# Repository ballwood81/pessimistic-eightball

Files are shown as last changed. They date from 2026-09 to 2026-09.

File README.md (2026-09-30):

# Pessimistic Eight Ball

A sarcastic fortune teller for the Seeed Studio XIAO nRF52840 Sense and Round Display for XIAO.

Shake it deliberately and the idle face gives way to a 900 ms mystic reveal. One of 48 yes, no, maybe, or ominous predictions remains visible for 15 seconds before the face returns.

Parametric enclosure source, printable parts, test coupons, and assembly notes
are in [cad/](cad/README.md).

## Hardware

- Seeed Studio XIAO nRF52840 Sense
- Seeed Studio Round Display for XIAO, 240 x 240 GC9A01
- USB data cable connected to the **XIAO USB-C port** for programming

The accelerometer is the XIAO Sense's onboard LSM6DS3TR-C. The Round Display provides the LCD, touch controller, RTC, and microSD slot.

The microSD card is not used. It is unnecessary for procedural graphics and static text, and Seeed documents support for FAT cards only up to 32 GB; the installed 64 GB card is outside that specification.

## Build and upload

Install the PlatformIO extension in VS Code, then run:

```powershell
pio run -e xiao_nrf52840_sense
pio run -e xiao_nrf52840_sense --target upload
```

If no USB serial device appears, ensure the cable is connected to the XIAO rather than the Round Display's power/charging USB-C port. Double-press the XIAO reset button to enter its UF2 bootloader, then retry upload.

## Tests

Logic tests cover shake discrimination, hit-window expiry, response repetition, reveal timing, busy-state lockout, and `millis()` rollover.

Run them on the attached XIAO:

```powershell
pio test -e xiao_tests
```

The `native` test environment is also configured, but requires `gcc` and `g++` on `PATH`:

```powershell
pio test -e native
```

## Tuning

Shake sensitivity is controlled by `ShakeConfig` in [include/eight_ball_logic.h](include/eight_ball_logic.h). Defaults require three acceleration deviations of at least 0.65 g within 400 ms. This rejects ordinary tilt because it uses acceleration magnitude rather than any single axis.

Predictions live in [include/responses.h](include/responses.h). Keep additions fairly short so they fit within six 20-character lines on the round display.

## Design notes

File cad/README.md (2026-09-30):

# Pessimistic Eight Ball enclosure

Parametric Build123d source for a PETG, 150 mm spherical enclosure. This is a
reviewable first-print design, not a verified production fit.

## Generate

Python 3.10 is the minimum; Python 3.11+ is recommended.

```powershell
python -m pip install -r cad/requirements.txt
python -m cad.export
```

Outputs are written to `cad/out/`:

- `upper_shell.{step,stl}`
- `lower_shell.{step,stl}`
- `usb_strain_relief.{step,stl}`
- `display_mount_coupon.{step,stl}`
- `bayonet_{female,male}_test_ring.{step,stl}`
- `battery_cradle_fit_test.{step,stl}`
- `assembled.step`, `exploded.step`
- `assembly_preview.png`, `exploded_preview.png`
- `verification.txt`

Edit `cad/params.py`, then regenerate. All dimensions are millimetres.

## Dimension status

Physically tested:

- Display aperture: **43.5 mm exactly**. No added clearance.
- Display support contact face: **9.0 mm** behind the exterior face.

Verified from both official Seeed Eagle boards:

- v1.0 and v1.1 mounting holes are identical: `(0, 19.431)`,
  `(11.811, -15.621)`, `(-11.811, -15.621)`, drill 2.2 mm.
- Printed ledge holes are 2.4 mm for M2 fit testing.
- Seeed describes the board as 39 mm. v1.1 changes the charge IC and adds the
  two-position switch; this model defaults to the larger v1.1 rear keep-out.
- Facing the glass, XIAO USB-C points right and the display switch is lower
  left, matching [Seeed's documented orientation][seeed].

Provisional and deliberately adjustable:

- 3.0 mm shell; 65 mm base footprint; 40 degree display angle.
- 2.5 mm curved ledges. Their shape follows the supplied screenshots: three
  local arcs around the 43.5 mm opening, with deeper root ribs. Screenshot
  construction points were not used as screw centres.
- Bayonet radial clearance 0.35 mm per side; axial 0.30 mm; tangential
  0.40 mm. Detent depth, clip retention, and shake resistance are untested.
- Battery pocket 0.6 mm clearance; clips 1.8 mm thick with 1.2 mm overlap.
- Moulded USB plug envelope 12.5 x 7 x 22 mm and 15 mm bend radius.
- Three-wire service connector envelope. `JST-XH 3-pin` is only a planning
  placeholder; set dimensions to the connector actually fitted.

## Design

The sphere is split at its equator. A derived internal collar carries three
120-degree bayonet lugs. Travel is 25 degrees. Entry slots have lead-ins;
tracks have positive end walls, radial detent bumps, and an inner wire guard.
One wide and one narrow seam notch form discreet insertion marks.

The upper face is a plane normal to a ray 40 degrees from vertical. Its
distance is derived from a 50 mm sphere chord. The 43.5 mm aperture is cut
normal to that plane. Three curved 2.5 mm ledges place their PCB contact faces
9 mm behind the exterior. Nut pockets are in thicker rear bosses, not in the
ledges.

Use three M2 x 6 mm pan-head screws and M2 nuts as the first stack trial:
1.6 mm reference PCB + 2.5 mm ledge + 1.6 mm nut. Verify the actual board,
head seating, nut engagement, and tip clearance before powering it. The
fasteners load the PCB mounting holes; they must not clamp the glass.

The reference snap case is 71.5 mm long and suits two loose cells with a gap
between them. This cradle is one channel for the shrink-wrapped pair: 4 mm
longer than that case, and 1 mm taller than the 19 mm pack body for the wrap.
Side hooks cam open and close over the pack. They stop before the 21 mm cable
end. There is no center divider. The cable end of the channel is open in the
middle. Route all three wires out that opening to a removable three-pin
connector inside the track guard.
Unplug it before separating the halves.

The rear upper-shell USB opening passes the full provisional moulded plug and
stays above the bayonet. Direct alignment to the sideways XIAO socket is not
practical in this geometry. Fit a short panel-free USB-C male-to-female
extension internally. Secure its cable jacket with the separate M2 strain
relief; do not transfer cable loads to the XIAO socket.

## Assembly order

1. Print and test the display coupon, bayonet rings, and battery cradle.
2. Install M2 nuts in the display bosses. Seat the Round Display without
   loading the active glass, fit the XIAO and headers, then install screws.
3. Fit the USB-C extension and clamp its jacket.
4. Push the battery into the lower cradle, cable end toward the configured
   `+X` end. Connect the removable three-wire lead and leave a service loop.
5. Keep the loop inside the guard, align seam marks, insert the upper half,
   rotate through the detent to the hard stop.
6. To service, rotate back, lift only enough to reach the connector, unplug,
   then separate fully.

## Printing

- Material: PETG. Start with 0.20 mm layers, 4 perimeters, and 5 top/bottom
  layers. Tune from coupons before printing shells.
- Upper shell: place the exterior display plane on the bed. Support is still
  required under portions of the inner sphere, root ribs, nut bosses, and
  bayonet roof. Block support from the 43.5 mm aperture and screw holes.
- Lower shell: flat base on the bed. Use local support only where the collar
  needs it. Clips print vertically so layer lines do not split across their
  root.
- Bayonet rings: flat annular face on the bed.
- Display coupon: exterior face on the bed.
- Battery coupon: cradle floor on the bed. Do not force the wrapped pack into
  an undersized print.

## Verification and outstanding checks

`python -m cad.export` fails if a printable body is not a valid closed solid,
the battery/clip envelope leaves the inner sphere, bayonet entry or locked
positions interfere, the detent has no engagement, the end stop has no
collision, or the USB plug path enters the collar.

CAD checks do not validate printer compensation, PETG creep, clip fatigue,
nut capture, connector orientation, touch access, cable flex life, detent
force, drop strength, or shake resistance. Print the three coupons first.
Measure the actual assembled XIAO/header depth and actual plug/connector before
the full shells.

## Attribution

Bayonet concepts are adapted from Johannes Hermann's
[AC Hose Bayonet Quick Connectors][bayonet], Apache-2.0. This version changes
the lug count, sections, fit model, path, stops, detents, wire guard, and
enclosure integration. See `NOTICE` and `LICENSE-Apache-2.0.txt`.

[bayonet]: https://github.com/jhermann/things/tree/main/models/ac-bayonet-connectors
[seeed]: https://wiki.seeedstudio.com/get_start_round_display/

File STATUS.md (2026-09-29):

# Project status — 2026-09-29 (LVGL polish)

## Diagnosis (pre-change)

| Symptom | Likely cause |
| --- | --- |
| Dirty / flicker | `fillScreen` + full idle-face redraw every 80 ms; no retained scene |
| Tear-ish lines earlier | wrong combo 666 (fixed) then heavy full-frame SPI |
| IMU false/miss | shake counted every sample above threshold with no hysteresis/cooldown; no shared lock vs touch |

## Shipped

- LVGL 8.3.11 + Seeed Round Display (`lv_xiao_*`) + Seeed_GFX combo **501**
- Persistent UI objects; fade + upward drift via `text_opa` / `y` (no full wipe)
- CHSC6X touch via Round Display LVGL indev; tap reveal / tap dismiss
- Shake: enter/exit hysteresis + hit window + cooldown; gated by `BallMachine`
- State: IDLE → TRIGGERED → REVEALING → VISIBLE → RESETTING → IDLE
- Responses unchanged
- Built + DFU flashed (RAM ~20%, flash ~28%)

## Physical test still needed

- Tap feel / debounce on glass
- Shake sensitivity on desk vs hand
- Reveal readability for longest ominous lines
- Auto-timeout vs tap-dismiss race

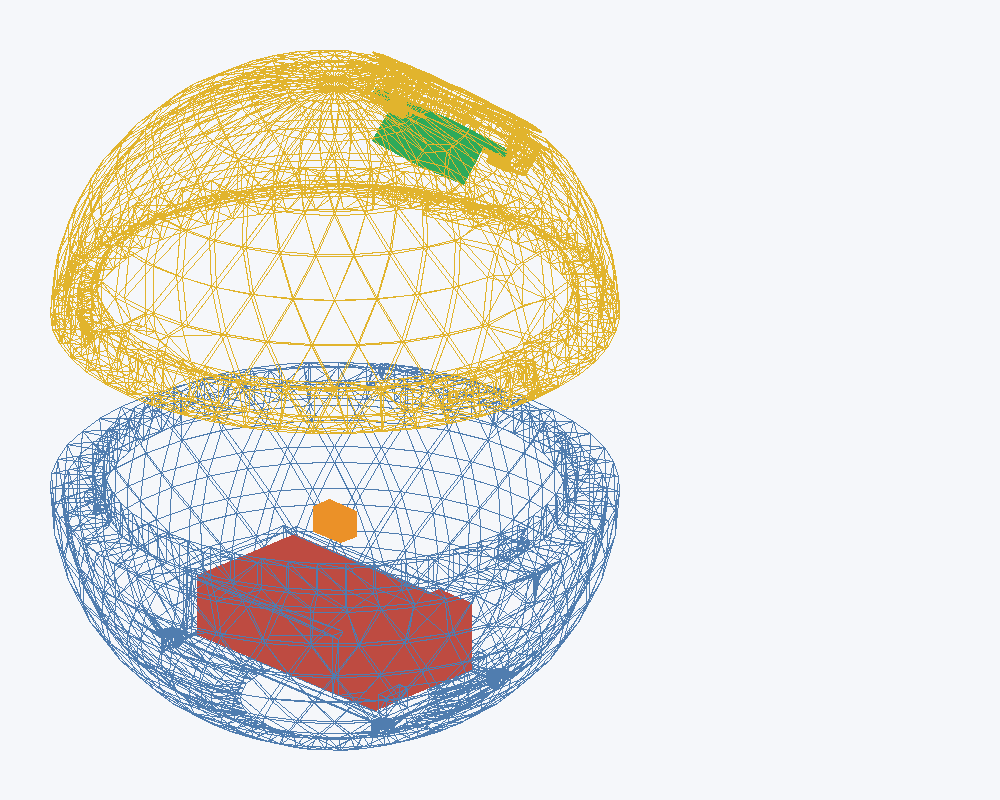
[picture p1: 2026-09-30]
cad/out/exploded_preview.png

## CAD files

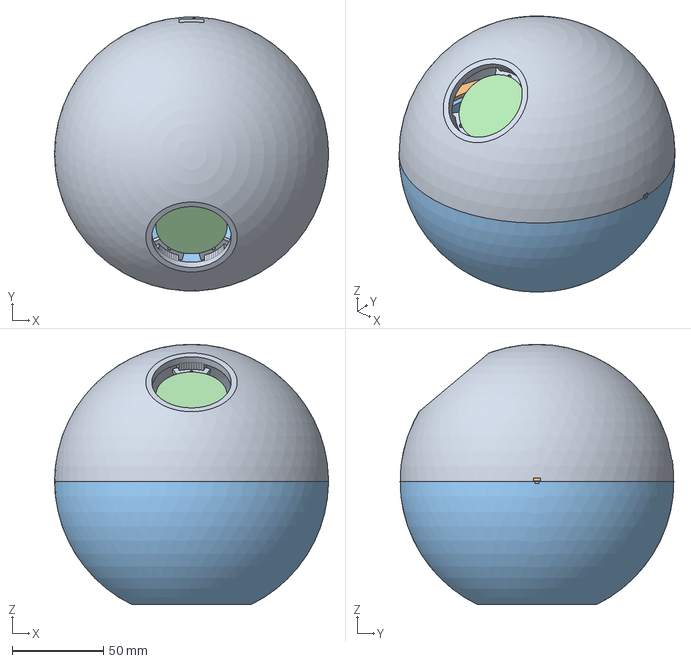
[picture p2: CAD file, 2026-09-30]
cad/out/assembled.step
150.0 x 149.8 x 142.6 mm

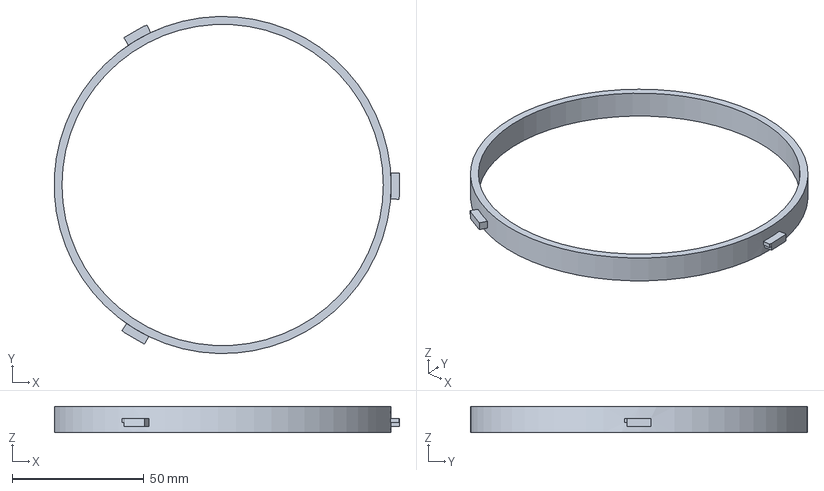
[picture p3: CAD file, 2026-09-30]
cad/out/bayonet_male_test_ring.step
131.0 x 127.8 x 10.0 mm

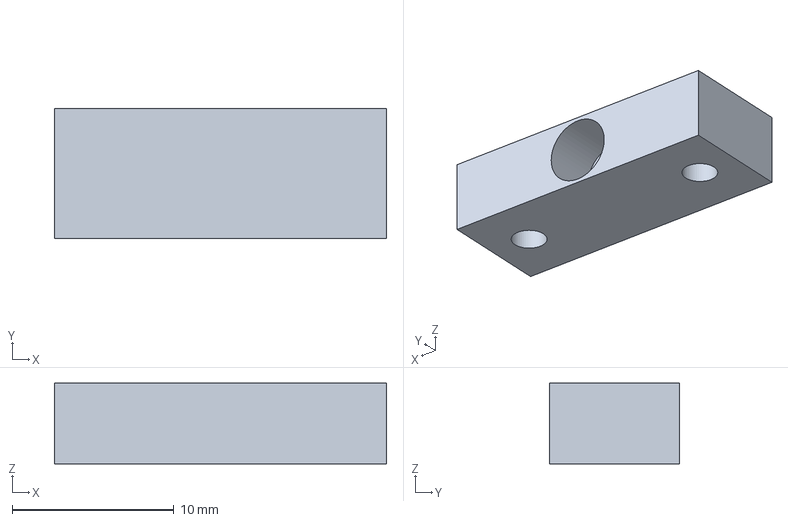
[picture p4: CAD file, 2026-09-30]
cad/out/usb_strain_relief.step
20.5 x 8.00 x 5.00 mm

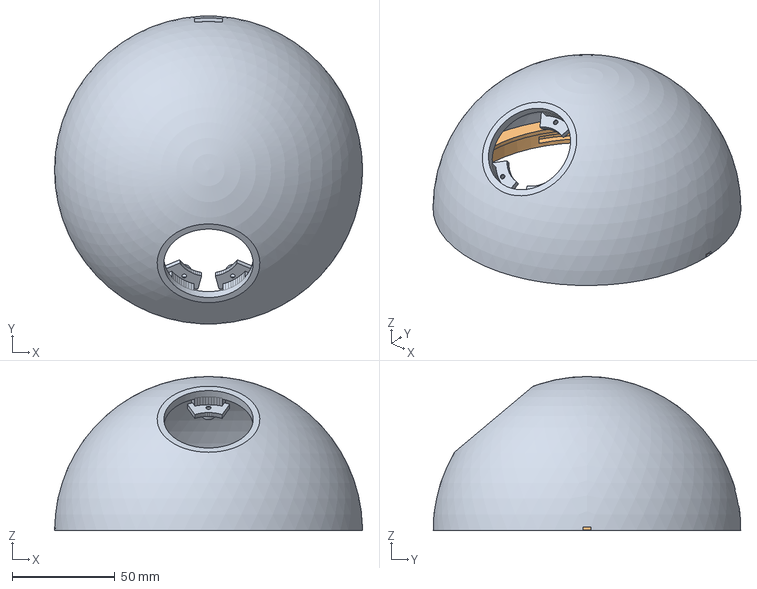
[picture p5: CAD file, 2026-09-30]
cad/out/upper_shell.step
150.0 x 149.8 x 75.0 mm

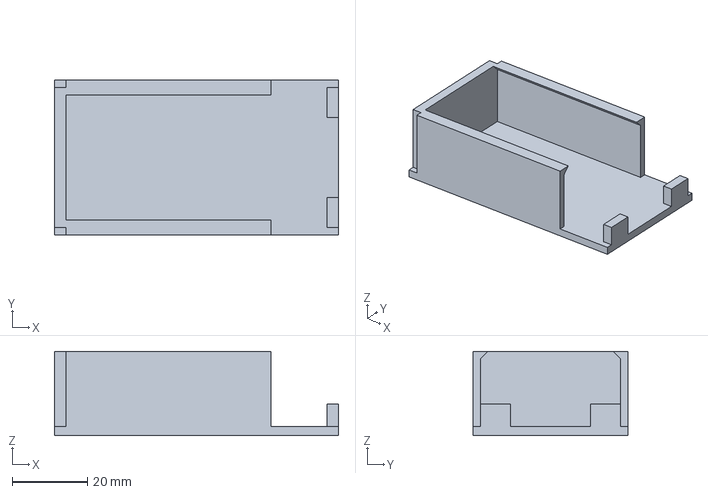
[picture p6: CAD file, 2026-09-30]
cad/out/battery_cradle_fit_test.step
75.5 x 41.2 x 22.4 mm

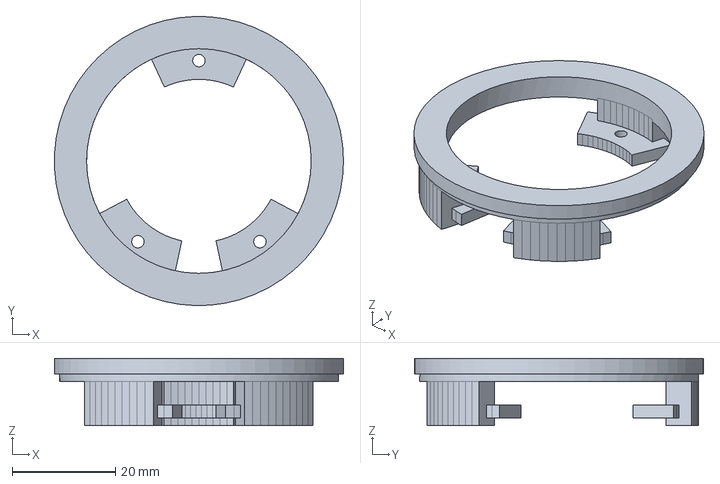
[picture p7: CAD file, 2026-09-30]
cad/out/display_mount_coupon.step
56.0 x 56.0 x 13.0 mm

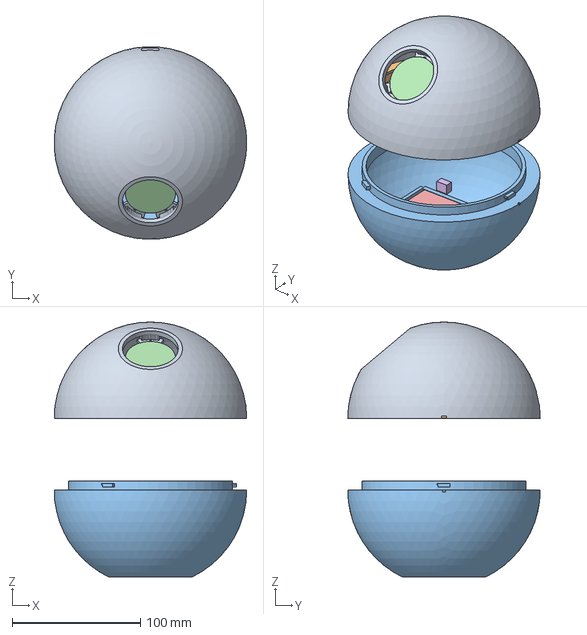
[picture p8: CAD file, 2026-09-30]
cad/out/exploded.step
149.9 x 149.9 x 198.6 mm

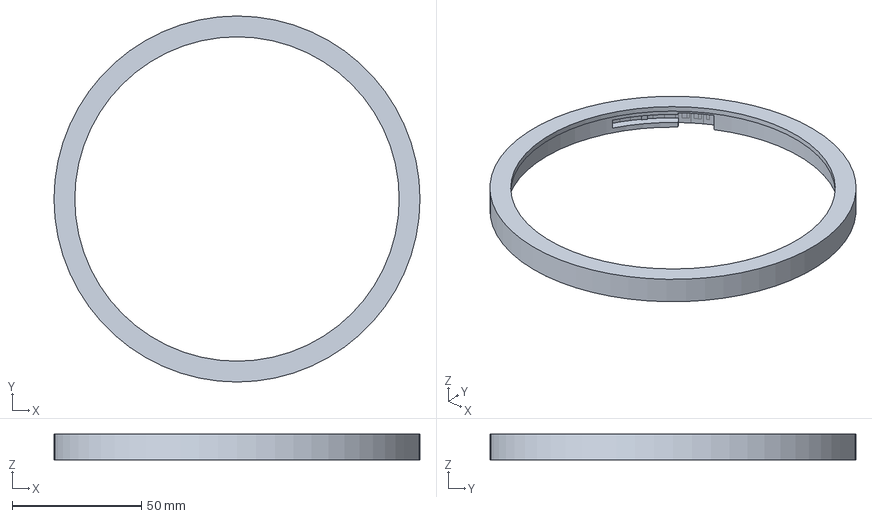
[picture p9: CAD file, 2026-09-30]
cad/out/bayonet_female_test_ring.step
141.7 x 141.7 x 10.0 mm

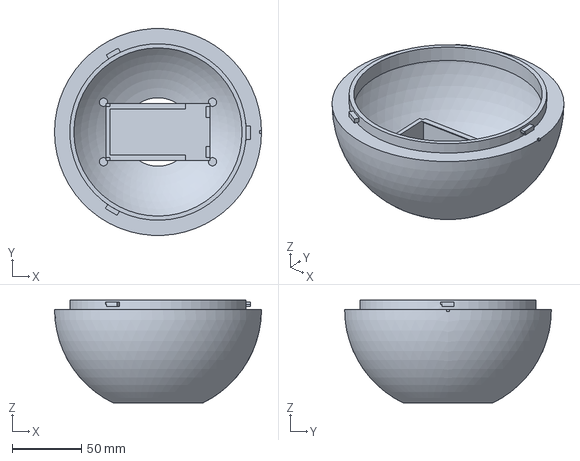
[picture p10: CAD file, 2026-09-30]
cad/out/lower_shell.step
150.0 x 149.8 x 74.6 mm

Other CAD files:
cad/out/battery_cradle_fit_test.stl
cad/out/bayonet_female_test_ring.stl
cad/out/bayonet_male_test_ring.stl
cad/out/display_mount_coupon.stl
cad/out/lower_shell.stl
cad/out/upper_shell.stl
cad/out/usb_strain_relief.stl

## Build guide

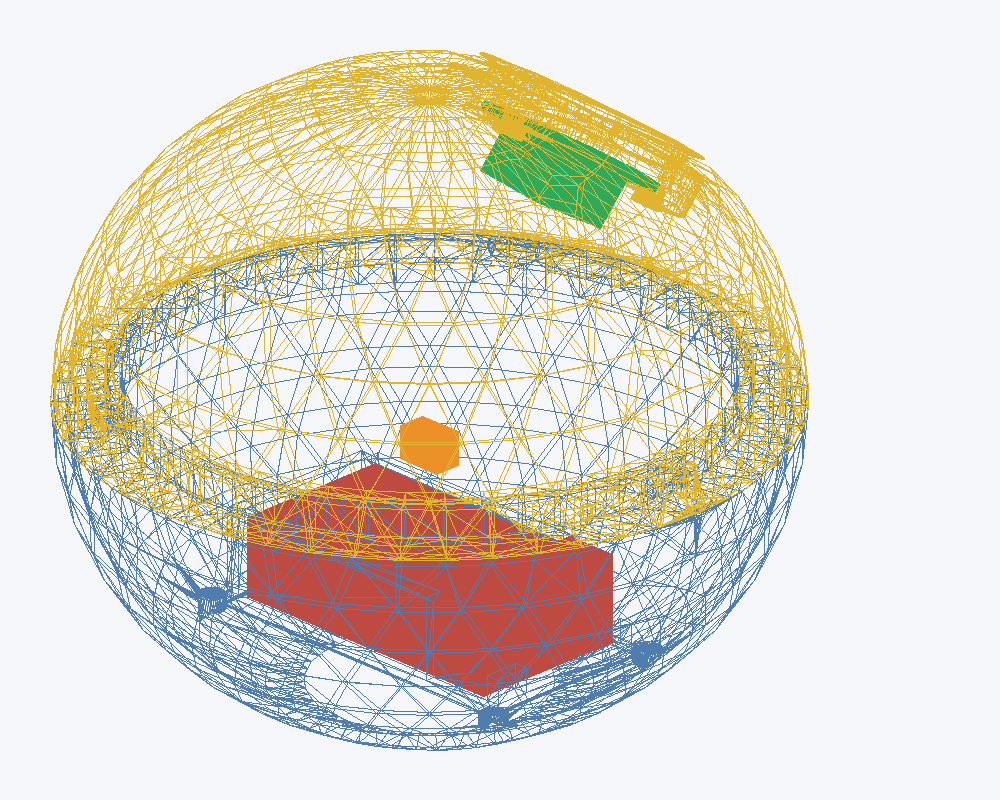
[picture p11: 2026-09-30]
cad/out/assembly_preview.png

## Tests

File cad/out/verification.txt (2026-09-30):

solids: valid closed solids
shell: 3.00 mm nominal
display: 43.5 mm aperture; 9.0 mm setback; 2.5 mm ledges
bayonet: entry 0.000 mm3; detent 5.496 mm3; locked 0.000 mm3; stop 135.508 mm3
battery: pack and clip swept envelope inside inner sphere
usb: plug path clears bayonet collar; internal extension required

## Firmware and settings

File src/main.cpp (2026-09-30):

#include <Adafruit_TinyUSB.h>
#include <Arduino.h>
#include <LSM6DS3.h>
#include <I2C_BM8563.h>
#include <Wire.h>
#include <cmath>
#include <cstdint>
#include <cstdio>

#include "driver.h"
#include <lvgl.h>
#include "lv_xiao_round_screen.h"

#include "eight_ball_logic.h"
#include "responses.h"

namespace {

constexpr std::uint32_t kImuIntervalMs = 20;
constexpr std::int16_t kSafeTextWidth = 168;
constexpr std::int16_t kRevealDriftPx = 18;
constexpr std::uint32_t kAnimMs = 700;

LSM6DS3 imu{I2C_MODE, 0x6A};
I2C_BM8563 rtc{I2C_BM8563_DEFAULT_ADDRESS, Wire};
bool rtc_ok = false;
void refresh_clock();
ShakeDetector shake_detector;
FaceOrient face_orient;
bool imu_ok = false;
ResponsePicker response_picker{kResponseCount};
BallMachine ball;

const Response* current_response = nullptr;
BallState previous_state = BallState::idle;
std::uint32_t last_imu_ms = 0;

lv_obj_t* scr = nullptr;
lv_obj_t* badge = nullptr;
lv_obj_t* eight_mark = nullptr;
lv_obj_t* window = nullptr;
lv_obj_t* eye_l = nullptr;
lv_obj_t* eye_r = nullptr;
lv_obj_t* pupil_l = nullptr;
lv_obj_t* pupil_r = nullptr;
lv_obj_t* mouth = nullptr;
lv_obj_t* clock_label = nullptr;
char clock_text[9] = "--:--:--";
lv_obj_t* kind_label = nullptr;
lv_obj_t* body_label = nullptr;

constexpr std::int16_t kEyeOpen = 28;
constexpr std::int16_t kEyeShut = 5;

lv_color_t kind_color(const ResponseKind kind) {
    switch (kind) {
        case ResponseKind::yes:
            return lv_color_hex(0x3d9b6e);
        case ResponseKind::no:
            return lv_color_hex(0xc44b4b);
        case ResponseKind::maybe:
            return lv_color_hex(0xc4843a);
        case ResponseKind::ominous:
            return lv_color_hex(0x9a5fb5);
    }
    return lv_color_hex(0xd8d0c4);
}

const char* kind_caption(const ResponseKind kind) {
    switch (kind) {
        case ResponseKind::yes:
            return "YES, SOMEHOW";
        case ResponseKind::no:
            return "ABSOLUTELY NOT";
        case ResponseKind::maybe:
            return "ANNOYINGLY MAYBE";
        case ResponseKind::ominous:
            return "THE VOID SAYS";
    }
    return "MYSTIC ERROR";
}

void set_response_hidden(const bool hidden) {
    if (hidden) {
        lv_obj_add_flag(kind_label, LV_OBJ_FLAG_HIDDEN);
        lv_obj_add_flag(body_label, LV_OBJ_FLAG_HIDDEN);
    } else {
        lv_obj_clear_flag(kind_label, LV_OBJ_FLAG_HIDDEN);
        lv_obj_clear_flag(body_label, LV_OBJ_FLAG_HIDDEN);
    }
}

void set_face_hidden(const bool hidden) {
    const lv_obj_t* parts[] = {badge, eye_l, eye_r, pupil_l, pupil_r, mouth, clock_label};
    for (const auto* part : parts) {
        if (hidden) {
            lv_obj_add_flag(const_cast<lv_obj_t*>(part), LV_OBJ_FLAG_HIDDEN);
        } else {
            lv_obj_clear_flag(const_cast<lv_obj_t*>(part), LV_OBJ_FLAG_HIDDEN);
        }
    }
}

void tick_face(const std::uint32_t now_ms) {
    if (ball.state() != BallState::idle) {
        return;
    }
    static std::uint32_t last_tick_ms = 0;
    if (now_ms - last_tick_ms < 80U) {
        return;
    }
    last_tick_ms = now_ms;

    const bool blink = (now_ms % 4300U) < 180U;
    const auto eye_h = static_cast<std::int16_t>(blink ? kEyeShut : kEyeOpen);
    lv_obj_set_height(eye_l, eye_h);
    lv_obj_set_height(eye_r, eye_h);

    constexpr std::int8_t looks[] = {-6, -3, 0, 4, 7, 2, -2};
    const auto look = looks[(now_ms / 700U) % 7U];
    if (blink) {
        lv_obj_add_flag(pupil_l, LV_OBJ_FLAG_HIDDEN);
        lv_obj_add_flag(pupil_r, LV_OBJ_FLAG_HIDDEN);
    } else {
        lv_obj_clear_flag(pupil_l, LV_OBJ_FLAG_HIDDEN);
        lv_obj_clear_flag(pupil_r, LV_OBJ_FLAG_HIDDEN);
        lv_obj_align(pupil_l, LV_ALIGN_CENTER, look, 0);
        lv_obj_align(pupil_r, LV_ALIGN_CENTER, look, 1);
    }

    const auto wobble = static_cast<std::int16_t>((now_ms / 550U) % 3U);
    lv_obj_align(mouth, LV_ALIGN_CENTER, 0, static_cast<std::int16_t>(46 + wobble));

    static std::uint32_t last_clock_ms = 0;
    if (!rtc_ok || now_ms - last_clock_ms < 1000U) {
        return;
    }
    last_clock_ms = now_ms;

    refresh_clock();
}

struct ClockStamp {
    int year = 0;
    int month = 0;
    int day = 0;
    int hours = 0;
    int minutes = 0;
    int seconds = 0;
};

int bcd_byte(const uint8_t value) {
    return static_cast<int>((value >> 4) * 10 + (value & 0x0F));
}

bool build_stamp(ClockStamp& out) {
    const char* date = __DATE__;
    const char* months = "JanFebMarAprMayJunJulAugSepOctNovDec";
    int month = 0;
    for (int i = 0; i < 12; ++i) {
        if (date[0] == months[i * 3] && date[1] == months[i * 3 + 1] && date[2] == months[i * 3 + 2]) {
            month = i + 1;
            break;
        }
    }
    if (month == 0) {
        return false;
    }
    out.month = month;
    out.day = (date[4] == ' ' ? 0 : date[4] - '0') * 10 + (date[5] - '0');
    out.year = (date[7] - '0') * 1000 + (date[8] - '0') * 100 + (date[9] - '0') * 10 + (date[10] - '0');
    out.hours = (__TIME__[0] - '0') * 10 + (__TIME__[1] - '0');
    out.minutes = (__TIME__[3] - '0') * 10 + (__TIME__[4] - '0');
    out.seconds = (__TIME__[6] - '0') * 10 + (__TIME__[7] - '0');
    return true;
}

bool stamp_sane(const ClockStamp& stamp) {
    return stamp.year >= 2026 && stamp.year <= 2035 && stamp.month >= 1 && stamp.month <= 12
        && stamp.day >= 1 && stamp.day <= 31 && stamp.hours <= 23 && stamp.minutes <= 59
        && stamp.seconds <= 59;
}

bool stamp_before(const ClockStamp& rtc, const ClockStamp& built) {
    if (rtc.year != built.year) {
        return rtc.year < built.year;
    }
    if (rtc.month != built.month) {
        return rtc.month < built.month;
    }
    if (rtc.day != built.day) {
        return rtc.day < built.day;
    }
    if (rtc.hours != built.hours) {
        return rtc.hours < built.hours;
    }
    if (rtc.minutes != built.minutes) {
        return rtc.minutes < built.minutes;
    }
    return rtc.seconds < built.seconds;
}

// nRF TWIM repeated-start can wait forever. Use a full stop between write and read.
bool read_stamp(ClockStamp& out, bool* voltage_low) {
    Wire.beginTransmission(I2C_BM8563_DEFAULT_ADDRESS);
    Wire.write(0x02);
    if (Wire.endTransmission() != 0) {
        return false;
    }
    if (Wire.requestFrom(static_cast<uint8_t>(I2C_BM8563_DEFAULT_ADDRESS), static_cast<uint8_t>(7)) != 7) {
        return false;
    }
    uint8_t raw[7];
    for (uint8_t& byte : raw) {
        byte = static_cast<uint8_t>(Wire.read());
    }
    if (voltage_low != nullptr) {
        *voltage_low = (raw[0] & 0x80) != 0;
    }
    out.seconds = bcd_byte(raw[0] & 0x7F);
    out.minutes = bcd_byte(raw[1] & 0x7F);
    out.hours = bcd_byte(raw[2] & 0x3F);
    out.day = bcd_byte(raw[3] & 0x3F);
    out.month = bcd_byte(raw[5] & 0x1F);
    out.year = ((raw[5] & 0x80) != 0 ? 1900 : 2000) + bcd_byte(raw[6]);
    return out.hours <= 23 && out.minutes <= 59;
}

// Three bytes only. A 7-byte read on this shared bus fails once touch polls, and the label stays put.
bool read_clock(int& hours, int& minutes, int& seconds) {
    Wire.beginTransmission(I2C_BM8563_DEFAULT_ADDRESS);
    Wire.write(0x02);
    if (Wire.endTransmission() != 0) {
        return false;
    }
    if (Wire.requestFrom(static_cast<uint8_t>(I2C_BM8563_DEFAULT_ADDRESS), static_cast<uint8_t>(3)) != 3) {
        return false;
    }
    const int raw_seconds = bcd_byte(static_cast<uint8_t>(Wire.read()) & 0x7F);
    const int raw_minutes = bcd_byte(static_cast<uint8_t>(Wire.read()) & 0x7F);
    const int raw_hours = bcd_byte(static_cast<uint8_t>(Wire.read()) & 0x3F);
    if (raw_hours > 23 || raw_minutes > 59 || raw_seconds > 59) {
        return false;
    }
    hours = raw_hours;
    minutes = raw_minutes;
    seconds = raw_seconds;
    return true;
}

void apply_stamp(const ClockStamp& stamp) {
    I2C_BM8563_DateTypeDef date{};
    date.year = static_cast<int16_t>(stamp.year);
    date.month = static_cast<int8_t>(stamp.month);
    date.date = static_cast<int8_t>(stamp.day);
    date.weekDay = 0;
    I2C_BM8563_TimeTypeDef time{};
    time.hours = static_cast<int8_t>(stamp.hours);
    time.minutes = static_cast<int8_t>(stamp.minutes);
    time.seconds = static_cast<int8_t>(stamp.seconds);
    rtc.WriteReg(0x00, 0x20);  // STOP=1 while the registers are written
    rtc.setDate(&date);
    rtc.setTime(&time);
    rtc.WriteReg(0x00, 0x00);  // STOP=0, oscillator runs
}

void refresh_clock() {
    int hours = 0;
    int minutes = 0;
    int seconds = 0;
    if (!read_clock(hours, minutes, seconds)) {
        return;
    }
    std::snprintf(clock_text, sizeof(clock_text), "%02d:%02d:%02d", hours, minutes, seconds);
    if (clock_label != nullptr) {
        lv_label_set_text(clock_label, clock_text);
    }
}

void place_response(const std::int16_t y_shift) {
    // Keep text opaque. A fade-to-zero on reroll left the labels invisible.
    lv_obj_set_style_text_opa(kind_label, LV_OPA_COVER, 0);
    lv_obj_set_style_text_opa(body_label, LV_OPA_COVER, 0);
    lv_obj_align(kind_label, LV_ALIGN_TOP_MID, 0, static_cast<std::int16_t>(78 + y_shift));
    lv_obj_align(body_label, LV_ALIGN_TOP_MID, 0, static_cast<std::int16_t>(108 + y_shift));
    lv_obj_invalidate(kind_label);
    lv_obj_invalidate(body_label);
}

void apply_reveal_visual(const float progress) {
    const auto y_off = static_cast<std::int16_t>(kRevealDriftPx * (1.0F - progress));
    place_response(y_off);
}

void apply_reset_visual(const float progress) {
    const auto opa = static_cast<lv_opa_t>((1.0F - progress) * LV_OPA_COVER);
    lv_obj_set_style_text_opa(kind_label, opa, 0);
    lv_obj_set_style_text_opa(body_label, opa, 0);
}

void show_idle() {
    current_response = nullptr;
    set_response_hidden(true);
    set_face_hidden(false);
    lv_obj_set_style_border_color(window, lv_color_hex(0xf4f4f4), 0);
    shake_detector.reset();
}

void begin_reveal() {
    const auto random_value = static_cast<std::uint32_t>(random(0x7FFFFFFF));
    current_response = &kResponses[response_picker.pick(random_value)];

    set_face_hidden(true);
    set_response_hidden(false);

    const auto accent = kind_color(current_response->kind);
    lv_obj_set_style_border_color(window, accent, 0);
    lv_obj_set_style_text_color(kind_label, accent, 0);
    lv_label_set_text(kind_label, kind_caption(current_response->kind));
    lv_label_set_text(body_label, current_response->text);
    lv_obj_move_foreground(kind_label);
    lv_obj_move_foreground(body_label);
    place_response(kRevealDriftPx);
}

void advance_from_triggered(const std::uint32_t now) {
    ball.update(now);  // TRIGGERED → REVEALING immediately
}

void on_screen_event(lv_event_t* event) {
    if (lv_event_get_code(event) != LV_EVENT_CLICKED) {
        return;
    }
    const auto now = millis();
    // Tap always re-rolls. Same habit as shaking a real 8-ball.
    if (ball.request_trigger(now)) {
        begin_reveal();
        advance_from_triggered(now);
    }
}

lv_obj_t* make_eye(lv_obj_t* parent, const std::int16_t x_ofs) {
    auto* eye = lv_obj_create(parent);
    lv_obj_set_size(eye, 36, kEyeOpen);
    lv_obj_set_style_radius(eye, 10, 0);
    lv_obj_set_style_bg_color(eye, lv_color_hex(0xf4f1ea), 0);
    lv_obj_set_style_bg_opa(eye, LV_OPA_COVER, 0);
    lv_obj_set_style_border_width(eye, 0, 0);
    lv_obj_set_style_pad_all(eye, 0, 0);
    lv_obj_clear_flag(eye, LV_OBJ_FLAG_SCROLLABLE);
    lv_obj_clear_flag(eye, LV_OBJ_FLAG_CLICKABLE);
    lv_obj_align(eye, LV_ALIGN_CENTER, x_ofs, -8);
    return eye;
}

lv_obj_t* make_pupil(lv_obj_t* eye) {
    auto* pupil = lv_obj_create(eye);
    lv_obj_set_size(pupil, 12, 12);
    lv_obj_set_style_radius(pupil, LV_RADIUS_CIRCLE, 0);
    lv_obj_set_style_bg_color(pupil, lv_color_hex(0x101820), 0);
    lv_obj_set_style_bg_opa(pupil, LV_OPA_COVER, 0);
    lv_obj_set_style_border_width(pupil, 0, 0);
    lv_obj_clear_flag(pupil, LV_OBJ_FLAG_SCROLLABLE);
    lv_obj_clear_flag(pupil, LV_OBJ_FLAG_CLICKABLE);
    lv_obj_align(pupil, LV_ALIGN_CENTER, 0, 0);
    return pupil;
}

void build_ui() {
    scr = lv_scr_act();
    lv_obj_set_style_bg_color(scr, lv_color_hex(0x050505), 0);
    lv_obj_set_style_bg_opa(scr, LV_OPA_COVER, 0);
    lv_obj_clear_flag(scr, LV_OBJ_FLAG_SCROLLABLE);
    lv_obj_clear_flag(scr, LV_OBJ_FLAG_CLICKABLE);

    window = lv_obj_create(scr);
    lv_obj_set_size(window, 240, 240);
    lv_obj_center(window);
    lv_obj_set_style_radius(window, LV_RADIUS_CIRCLE, 0);
    lv_obj_set_style_bg_color(window, lv_color_hex(0x071018), 0);
    lv_obj_set_style_bg_opa(window, LV_OPA_COVER, 0);
    lv_obj_set_style_border_width(window, 6, 0);
    lv_obj_set_style_border_color(window, lv_color_hex(0xf4f4f4), 0);
    lv_obj_set_style_pad_all(window, 0, 0);
    lv_obj_clear_flag(window, LV_OBJ_FLAG_SCROLLABLE);
    lv_obj_add_flag(window, LV_OBJ_FLAG_CLICKABLE);
    lv_obj_add_event_cb(window, on_screen_event, LV_EVENT_CLICKED, nullptr);

    // 8 sits on the forehead, between the eyes. Smaller than the old shell badge.
    badge = lv_obj_create(window);
    lv_obj_set_size(badge, 40, 40);
    lv_obj_align(badge, LV_ALIGN_CENTER, 0, -54);
    lv_obj_set_style_radius(badge, LV_RADIUS_CIRCLE, 0);
    lv_obj_set_style_bg_color(badge, lv_color_hex(0xf7f7f7), 0);
    lv_obj_set_style_bg_opa(badge, LV_OPA_COVER, 0);
    lv_obj_set_style_border_width(badge, 0, 0);
    lv_obj_clear_flag(badge, LV_OBJ_FLAG_SCROLLABLE);
    lv_obj_clear_flag(badge, LV_OBJ_FLAG_CLICKABLE);

    eight_mark = lv_label_create(badge);
    lv_label_set_text(eight_mark, "8");
    lv_obj_set_style_text_font(eight_mark, &lv_font_montserrat_28, 0);
    lv_obj_set_style_text_color(eight_mark, lv_color_hex(0x111111), 0);
    lv_obj_align(eight_mark, LV_ALIGN_CENTER, 0, 0);
    lv_obj_clear_flag(eight_mark, LV_OBJ_FLAG_CLICKABLE);

    eye_l = make_eye(window, -46);
    eye_r = make_eye(window, 46);
    pupil_l = make_pupil(eye_l);
    pupil_r = make_pupil(eye_r);

    // Frown: arc through 12 o'clock (bulge up, corners down).
    mouth = lv_arc_create(window);
    lv_obj_set_size(mouth, 88, 88);
    lv_arc_set_bg_angles(mouth, 220, 320);
    lv_arc_set_value(mouth, 0);
    lv_obj_remove_style(mouth, nullptr, LV_PART_KNOB);
    lv_obj_set_style_arc_width(mouth, 4, LV_PART_MAIN);
    lv_obj_set_style_arc_color(mouth, lv_color_hex(0xd06a28), LV_PART_MAIN);
    lv_obj_set_style_arc_width(mouth, 0, LV_PART_INDICATOR);
    lv_obj_clear_flag(mouth, LV_OBJ_FLAG_CLICKABLE);
    lv_obj_align(mouth, LV_ALIGN_CENTER, 0, 46);

    clock_label = lv_label_create(window);
    lv_label_set_text(clock_label, clock_text);
    lv_obj_set_style_text_font(clock_label, &lv_font_montserrat_28, 0);
    lv_obj_set_style_text_color(clock_label, lv_color_hex(0x8a8478), 0);
    lv_obj_align(clock_label, LV_ALIGN_CENTER, 0, 68);
    lv_obj_clear_flag(clock_label, LV_OBJ_FLAG_CLICKABLE);

    kind_label = lv_label_create(window);
    lv_label_set_text(kind_label, "");
    lv_obj_set_width(kind_label, kSafeTextWidth);
    lv_obj_set_style_text_align(kind_label, LV_TEXT_ALIGN_CENTER, 0);
    lv_obj_set_style_text_font(kind_label, &lv_font_montserrat_12, 0);
    lv_obj_set_style_text_letter_space(kind_label, 1, 0);
    lv_obj_align(kind_label, LV_ALIGN_TOP_MID, 0, 78);
    lv_obj_clear_flag(kind_label, LV_OBJ_FLAG_CLICKABLE);

    body_label = lv_label_create(window);
    lv_label_set_text(body_label, "");
    lv_obj_set_width(body_label, kSafeTextWidth);
    lv_label_set_long_mode(body_label, LV_LABEL_LONG_WRAP);
    lv_obj_set_style_text_align(body_label, LV_TEXT_ALIGN_CENTER, 0);
    lv_obj_set_style_text_font(body_label, &lv_font_montserrat_14, 0);
    lv_obj_set_style_text_color(body_label, lv_color_hex(0xe6e0d6), 0);
    lv_obj_set_style_text_line_space(body_label, 3, 0);
    lv_obj_align(body_label, LV_ALIGN_TOP_MID, 0, 108);
    lv_obj_clear_flag(body_label, LV_OBJ_FLAG_CLICKABLE);

    set_response_hidden(true);
}

void on_state_entered(const BallState state) {
    switch (state) {
        case BallState::idle:
            show_idle();
            break;
        case BallState::triggered:
        case BallState::revealing:
            // begin_reveal already called from trigger paths
            break;
        case BallState::visible:
            apply_reveal_visual(1.0F);
            shake_detector.reset();  // answer is up — next shake can count
            break;
        case BallState::resetting:
            break;
    }
}

Acceleration read_imu() {
    return {imu.readFloatAccelX(), imu.readFloatAccelY(), imu.readFloatAccelZ()};
}

void apply_screen_rotation(const std::uint8_t rot) {
    if (rot == screen_rotation) {
        return;
    }
    screen_rotation = rot;
    tft.setRotation(rot);
    if (scr != nullptr) {
        lv_obj_invalidate(scr);
        lv_refr_now(nullptr);
    }
    Serial.print("face rot=");
    Serial.println(rot);
}

// Blocks until ~2s of quiet gravity, or 10s. Shakes are skipped. Fallback is rotation 0.
std::uint8_t lock_screen_rotation() {
    MountLock lock;
    const MountLockConfig config;
    const auto started = millis();
    while (millis() - started < config.deadline_ms) {
        if (lock.add(read_imu(), millis(), config)) {
            break;
        }
        delay(20);
    }
    const auto rot = lock.rotation(config);
    const float inv = lock.still_ms == 0 ? 0.0F : 1.0F / static_cast<float>(lock.still_ms);
    Serial.print("mount still_ms=");
    Serial.print(lock.still_ms);
    Serial.print(" ax=");
    Serial.print(lock.sum_x * inv, 2);
    Serial.print(" ay=");
    Serial.print(lock.sum_y * inv, 2);
    Serial.print(" az=");
    Serial.print(lock.sum_z * inv, 2);
    Serial.print(" rot=");
    Serial.println(rot);
    return rot;
}

}  // namespace

void setup() {
    Serial.begin(115200);

    // screen_rotation is latched in lv_xiao_disp_init, so the IMU has to run first.
    // Rail stays off and Wire1 waits forever if this pin is low.
    pinMode(PIN_LSM6DS3TR_C_POWER, OUTPUT);
    digitalWrite(PIN_LSM6DS3TR_C_POWER, HIGH);
    delay(20);
    imu_ok = imu.begin() == 0;
    if (!imu_ok) {
        Serial.println("IMU NOT FOUND");
        screen_rotation = 0;
    } else {
        Serial.println("IMU ok");
        screen_rotation = lock_screen_rotation();
    }

    lv_init();
    lv_xiao_disp_init();
    lv_xiao_touch_init();
    build_ui();
    show_idle();
    for (std::uint8_t frame = 0; frame < 4; ++frame) {
        lv_timer_handler();
        delay(10);
    }

    // Touch and the BM8563 share Wire. IMU stays on Wire1.
    // ponytail: seed when VL is set, the date is garbage, or this firmware is newer
    // than the RTC. A later reboot keeps coin-cell time. Ceiling: no clock newer than
    // the build survives a dead cell; flash again to restamp.
    ClockStamp running{};
    ClockStamp built{};
    bool voltage_low = false;
    rtc_ok = read_stamp(running, &voltage_low);
    if (rtc_ok) {
        rtc.begin();
        if (build_stamp(built)
            && (voltage_low || !stamp_sane(running) || stamp_before(running, built))) {
            apply_stamp(built);
            Serial.println("RTC seeded from build time");
        }
        refresh_clock();
        Serial.println("RTC ok");
    } else {
        Serial.println("RTC NOT FOUND");
    }

    const auto seed = static_cast<unsigned long>(
        micros() ^ static_cast<std::uint32_t>(std::fabs(imu.readFloatAccelX()) * 100000.0F));
    randomSeed(seed);

    if (imu_ok) {
        face_orient.arm(millis());
    }

    Serial.println("pessimistic eight-ball ready");
}

void loop() {
    const auto now_ms = millis();
    ball.update(now_ms);
    const auto state = ball.state();

    if (state != previous_state) {
        previous_state = state;
        on_state_entered(state);
    }

    if (state == BallState::idle) {
        tick_face(now_ms);
    } else if (state == BallState::revealing) {
        apply_reveal_visual(ball.phase_progress(now_ms));
    } else if (state == BallState::resetting) {
        apply_reset_visual(ball.phase_progress(now_ms));
    }

    if (ball.accepts_shake() && now_ms - last_imu_ms >= kImuIntervalMs) {
        last_imu_ms = now_ms;
        if (shake_detector.update(read_imu(), now_ms)) {
            if (ball.request_trigger(now_ms)) {
                begin_reveal();
                advance_from_triggered(now_ms);
            }
        }
    }

    if (imu_ok && face_orient.wants_sample(now_ms)) {
        const Acceleration sample = read_imu();
        std::uint8_t rot = screen_rotation;
        const bool turn = face_orient.update(sample, now_ms, screen_rotation, rot);
        Serial.print("grav ax=");
        Serial.print(sample.x_g, 2);
        Serial.print(" ay=");
        Serial.print(sample.y_g, 2);
        Serial.print(" az=");
        Serial.print(sample.z_g, 2);
        Serial.print(" up=");
        Serial.print(screen_up_g(sample), 2);
        Serial.print(" rot=");
        Serial.println(turn ? rot : screen_rotation);
        if (turn) {
            apply_screen_rotation(rot);
        }
    }

    static std::uint32_t last_beat_ms = 0;
    if (now_ms - last_beat_ms >= 2000U) {
        last_beat_ms = now_ms;
        Serial.print("alive state=");
        Serial.println(static_cast<int>(state));
    }

    lv_timer_handler();
    delay(5);  // Seeed Round Display examples — keeps LVGL tick healthy
    (void)kAnimMs;
}
